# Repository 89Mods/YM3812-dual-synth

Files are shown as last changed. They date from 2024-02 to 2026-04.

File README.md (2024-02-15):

# YM3812-dual-synth
MIDI synthesizer built from two YM3812s for 18-voice mono or 9-voice stereo. More info: https://tholin.dev/ym3812d/

# Build instructions

## PCB

The gerber file for the synthesizer can be found [here](https://github.com/89Mods/YM3812-dual-synth/tree/main/KiCad/production) and you should be able to use this with all the major board houses. Just make sure they correctly recognize it as a 4-layer PCB. The dimensions of the PCB are low enough to where it should be cheap despite it being 4-layers (8€ on JLCPCB).

## Parts

The YM3812s and their DACs are the most annoying parts to obtain. They can be easily found on eBay and AliExpress by simply using "YM3812" and "Y3014" keywords, but the condition of the parts can vary. The AliExpress listings I bought from are [here](https://de.aliexpress.com/item/1005001723547967.html) and [here.](https://de.aliexpress.com/item/1005002637379806.html)

The nanoCH32V003 mini dev board you can maybe even find at your favorite maker shop, but also [on AliExpress](https://de.aliexpress.com/item/1005005221751705.html). If there is an option to buy the board plus a "WCHLinkE" you may use that (recommended), but I will also show you how to use an Arduino Uno to flash the synthesizer firmware later on (though this requires a Linux install or WSL).

All the other integrated circuits can be found at various electronics retailers:

LM358: [TME](https://www.tme.eu/de/details/lm358ap/tht-operationsverstarker/texas-instruments/) - [Mouser](https://www.mouser.de/ProductDetail/Texas-Instruments/LM358N-NOPB?qs=QbsRYf82W3GXbWt%2FvwDTcQ%3D%3D) - [LCSC](https://www.lcsc.com/product-detail/Operational-Amplifier_HGSEMI-LM358N_C434570.html)

6N139 (or 6N138): [TME](https://www.tme.eu/de/details/6n139-eve/optokoppler-analogausgang/everlight/6n139/) - [Mouser](https://www.mouser.de/ProductDetail/Vishay-Semiconductors/6N139?qs=WHRYDAs2thAk3qh0MF5UBQ%3D%3D) - [LCSC](https://www.lcsc.com/product-detail/Optocouplers-Logic-Output_CT-Micro-International-6N139_C191869.html)

SN74LV1T34DBVRG4: [TME](https://www.tme.eu/de/details/sn74lv1t34dbvrg4/logische-wandler/texas-instruments/) - [Mouser](https://www.mouser.de/ProductDetail/Texas-Instruments/SN74LV1T34DBVRG4?qs=vdi0iO8H4N10R%252Bt%252BjmxZrg%3D%3D) - [LCSC](https://www.lcsc.com/product-detail/Buffer-Driver-Transceiver_Texas-Instruments-SN74LV1T34DBVR_C100024.html)

MX25L1005 (or MX25L2006 or 25Q32 or any spiflash that supports the 25xx command set and is made by Winbond or Macronix): [TME](https://www.tme.eu/de/details/mx25l2006em1i-12g/serielle-flash-speicher/macronix-international/mx25l2006em1i-12g-tube/) - [LCSC](https://www.lcsc.com/product-detail/NOR-FLASH_MXIC-Macronix-MX25L2006EM1I-12G_C135940.html) - I also recommend looking for "MX25L1005" on AliExpress, you can get them really cheap there.

74HCT164 (or 74LS164, NOT 74HC164): [TME](https://www.tme.eu/de/details/cd74hct164e/schieberegister/texas-instruments/) - [Mouser](https://www.mouser.de/ProductDetail/Texas-Instruments/SN74LS164NE4?qs=SL3LIuy2dWzMustM9SNFlQ%3D%3D) - [LCSC](https://www.lcsc.com/product-detail/Shifting-Register_Texas-Instruments-SN74LS164N_C129807.html)

## Build notes

The BOM for assembling the board is available [here](https://example.com/). Otherwise, there is little special to keep in mind, just solder the SMD components first, and use pin sockets for the nanoCH. It needs to be removed from the synthesizer to be re-flashed.

The 5-pin header at the bottom of the board is where MIDI input is. You will need to wire in a broken-out MIDI connector here. Only two need to actually be wired up. The 2nd pin from the left wires to the Current Sink on the MIDI connector and the 4th pin from the left to Current Source.

## Flashing Firmware

This step changes depending on if you’re running Windows or Linux, and if you have bought the WCHLinkE. In any case, you will need the minichlink utility.

If you are running Linux, it is part of a repo [here](https://github.com/cnlohr/ch32v003fun/tree/master/minichlink) and can be built using the makefile there. Also read the readme there for instructions on installing the required udev rules.

If you are running windows, download the pre-built executable files [here](https://github.com/cnlohr/ch32v003fun/blob/master/minichlink/minichlink.exe) and [here](https://github.com/cnlohr/ch32v003fun/blob/master/minichlink/libusb-1.0.dll) (you need both files).

A pre-built binary of the synthesizer’s firmware is [here](https://github.com/89Mods/YM3812-dual-synth/blob/main/RV_Firmware/synth.bin). To use a WCH-LinkE to flash it, wire up the single-wire IO pin of the programmer (labeled "SWDIO" or similar) to the SWIO pin of the nanoCH (the middle of the three-pin header on the back). To then use it to flash the firmware file, the command-line `minichlink(.exe) -w synth.bin flash -b` should work on either OS, and you are already done.

If you did not buy the WCHLinkE, but have an Arduino Uno laying around, you can use Ardulink. It is available on its own repo [here](https://gitlab.com/BlueSyncLine/arduino-ch32v003-swio). Follow the instructions there to set it up. Note that it requires a Linux install or WSL to build, but can be *used* from either OS.
Additionally, the repo mentions connecting the nanoCH’s power to an Arduino pin, but I’ve found that to be really unstable and it still works fine with the nanoCH powered continuously. You only need to wire up SWIO to the Arduino (its the middle pin of the three-pin header on top).

On Windows: `minichlink.exe -c COMx -w synth.bin flash -b` where "COMx" needs to be substituted with whichever COM port your Arduino uses.

On Linux: `minichlink -c /dev/ttyACMx -w synth.bin flash -b` where "ttyACMx" needs to be substituted with whichever tty port your Arduino uses.

## Uploading patches

A set of patches for all standard MIDI instruments must be uploaded to the synthesizer at least once. A public-domain file containing patches is included in this repo: [GENMIDI.op2](https://github.com/89Mods/YM3812-dual-synth/blob/main/PatchUploader/GENMIDI.op2). You can edit this to your liking using the [OPL3 Bank Editor](https://github.com/Wohlstand/OPL3BankEditor) (scroll down and use one of the "Fresh dev builds", the latest GitHub release is years old and has issues).

A custom tool I made can then be used to send this data to the synthesizer over the MIDI port. [PatchUploader.jar](https://github.com/89Mods/YM3812-dual-synth/blob/main/PatchUploader/PatchUploader.jar) (requires Java 11 or higher). If your system does not already associate .jar files with Java, you may need to run it through a command line with `java -jar PatchUploader.jar`

The UI should be straight forward. After selecting the the .op2 file and the MIDI port of the synthesizer, click the upload button and you should see activity on the synthesizer in the form of a flashing blue LED on the nanoCH. It should flash multiple times and the synth should then reset and play a jingle. If nothing happens, check if the MIDI port is wired up correctly and if any software or hardware in your setup is potentially blocking the sysex messages used by the uploader.

The uploader software releases the MIDI port when it is done, meaning you can keep it open and use it multiple times by just clicking the button again. The file is also re-loaded each time and does not need to be selected again.

## Switching Modes

The synthesizer can operate in three distinct modes.

**Mono**: both sound chips are combined into a single output. This allows their voices to be used together, 18 in total. This is the most basic and default mode.

**Stereo**: every note is played on both chips simultaniously, but its volume on either chip is adjusted according to the MIDI channel’s stereo pan, giving the illusion of stereo audio. This, however, reduced the amount of usable voices back to 9.

**Independent**: each chip acts as a separate synthesizer. Each responds only to events on a specific range of MIDI channels and their outputs can be individually obtained on the same output as the stereo audio.

MIDI sysex messages are used to switch between these. The codes are as follows:

Switch to Mono: `0xF0 0x7E 0x56 0x72 0xF7`

Switch to Stereo: `0xF0 0x7E 0x56 0x76 0xF7`

Switch to Independent: `0xF0 0x7E 0x56 0x75 0xF7`

By default, the synthesizer listens to all channels in Mono and Stereo modes and in Independent mode, channels 1 - 8 will go to the first chip and 9 - 16 to the second. An alternative firmware image is available [here](https://github.com/89Mods/YM3812-dual-synth/blob/main/RV_Firmware/synth_alt.bin) where the synthesizer only listens to channel 15 in Mono and Stereo and in Independent, channel 14 goes to the first and channel 15 to the second chip.

To fully customize this behavior, you will need to build the firmware yourself, after editing `synth.c` and changing the values in the `accepted_channels` array for Mono and Stereo and `accepted_channels_first` and `accepted_channels_second` for Independent. These are right at the beginning of the file and are just lists of MIDI channels (warning: 0-indexed).

## Building the firmware from source

If you want to build the firmware from source, it has do be done on a native Linux install, or in Windows Subsystem for Linux. You will need to install the [RISC-V GNU Toolchain](https://github.com/riscv-collab/riscv-gnu-toolchain) first, though this step varies between distros. I recommend cloning the repo and building it from source, as that is what worked for me.

Then, clone this repo and execute the script to set up the environment: `sh clone_subrepos_and_patch.sh`

Then, you can enter the RV_Firmware directory and use the makefile there. Simply `make` will both build the firmware and then flash the output using minichlink.

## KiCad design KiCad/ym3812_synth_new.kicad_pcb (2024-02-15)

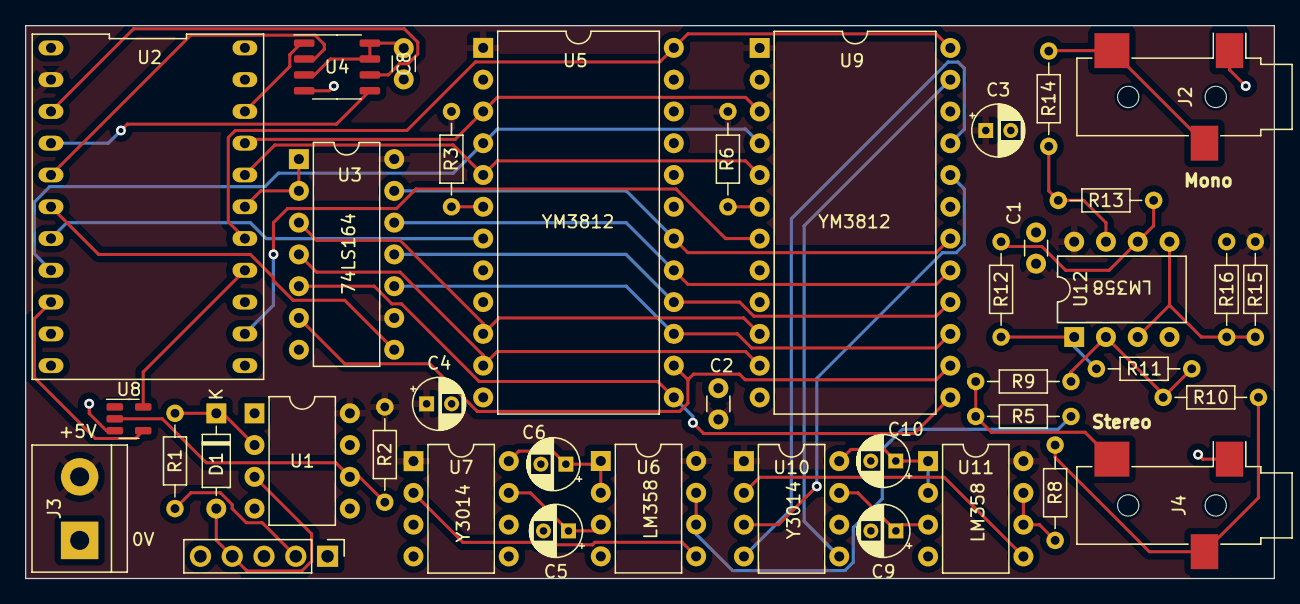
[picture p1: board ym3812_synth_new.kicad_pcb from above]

Board: 4 copper layers, 99.8 x 44.2 mm, 40 parts (0 on the bottom side), 52 nets.

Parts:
C1, C2, C8: 100nF; C_Disc_D3.0mm_W1.6mm_P2.50mm
C3, C4, C5, C6, C9, C10: 10µF; CP_Radial_D4.0mm_P2.00mm
D1: 1N4148; D_DO-35_SOD27_P7.62mm_Horizontal
J1: DIN-5; PinHeader_1x05_P2.54mm_Vertical
J2, J4: AudioJack3; Jack_3.5mm_CUI_SJ-3523-SMT_Horizontal
J3: Screw_Terminal_01x02; TerminalBlock_bornier-2_P5.08mm
R1, R2, R3, R6: 220; R_Axial_DIN0204_L3.6mm_D1.6mm_P7.62mm_Horizontal
R5, R8, R14: 1K; R_Axial_DIN0204_L3.6mm_D1.6mm_P7.62mm_Horizontal
R9, R10, R11, R12, R13: 100K; R_Axial_DIN0204_L3.6mm_D1.6mm_P7.62mm_Horizontal
R15, R16: 10K; R_Axial_DIN0204_L3.6mm_D1.6mm_P7.62mm_Horizontal
U1: 6N139; DIP-8_W7.62mm
U2: nanoCH32V003; DIP-22_610_ELL
U3: 74HCT164; DIP-14_W7.62mm
U4: MX25L1005; SOP-8_3.9x4.9mm_P1.27mm
U5, U9: YM3812; DIP-24_W15.24mm
U6, U11, U12: LM358; DIP-8_W7.62mm
U7, U10: Y3014; DIP-8_W7.62mm
U8: SN74LV1T34DCK; SOT-23-5

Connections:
4MHz: U2.16 (D0), U5.24 (φM), U9.24 (φM)
+3.3V: C8.1, U2.15 (3V3), U4.3 (~WP), U4.7 (~HOLD), U4.8 (Vcc), U8.5 (VCC)
+5V: C1.1, C2.1, C3.1, C4.1, J3.2, R2.2, R3.2, R6.2, R15.1, U1.8 (VCC), U2.2 (5V), U3.9 (~MR), U3.14 (VCC), U5.1 (Vss), U6.8 (V+), U7.1 (Vcc), U9.1 (Vss), U10.1 (Vcc), U11.8 (V+), U12.8 (V+)
A0: U2.8 (D4), U5.4 (A0), U9.4 (A0)
GND: C1.2, C2.2, C3.2, C4.2, C5.2, C6.2, C8.2, C9.2, C10.2, J2.S, J3.1, J4.S, R16.2, U1.5 (GND), U2.1 (GND), U2.22 (GND), U3.7 (GND), U4.4 (GND), U5.12 (GND), U6.4 (V-), U7.6 (GND), U8.3 (GND), U9.12 (GND), U10.6 (GND), U11.4 (V-), U12.4 (V-)
unnamed: D1.2 (A), J1.4, U1.3 (C2)
unnamed: D1.1 (K), R1.2, U1.2 (C1)
unnamed: J1.2, R1.1
unnamed: J2.R, J2.T, R14.1
unnamed: R11.1, R12.2, U12.1
unnamed: R13.1, R14.2, U12.7
unnamed: R2.1, U1.6 (VO2), U8.2 (A)
unnamed: U2.17 (C0), U3.1 (DSA), U3.2 (DSB)
unnamed: U2.6 (D2), U3.8 (CP)
unnamed: U2.9 (D5), U8.4 (Y)
unnamed: U5.21 (MO), U7.4 (SD)
unnamed: U5.20 (SH), U7.3 (LD)
unnamed: R3.1, U5.6 (~RD)
unnamed: U5.23 (φSY), U7.5 (CLK)
unnamed: C5.1, U6.3 (+), U7.7 (RB)
unnamed: C6.1, U6.1, U6.2 (-), U7.8 (MP)
unnamed: U6.5 (+), U7.2 (Out)
unnamed: R5.2, U6.6 (-), U6.7
unnamed: R6.1, U9.6 (~RD)
unnamed: U9.23 (φSY), U10.5 (CLK)
unnamed: U9.20 (SH), U10.3 (LD)
unnamed: C10.1, U10.8 (MP), U11.1, U11.2 (-)
unnamed: U10.2 (Out), U11.5 (+)
unnamed: C9.1, U10.7 (RB), U11.3 (+)
unnamed: U9.21 (MO), U10.4 (SD)
unnamed: R8.2, U11.6 (-), U11.7
unnamed: R15.2, R16.1, U12.3 (+), U12.5 (+)
unnamed: R9.1, R10.1, R11.2, U12.2 (-)
unnamed: R12.1, R13.2, U12.6 (-)
Q0: U3.3 (Q0), U5.10 (D0), U9.10 (D0)
Q1: U3.4 (Q1), U5.11 (D1), U9.11 (D1)
Q2: U3.5 (Q2), U5.13 (D2), U9.13 (D2)
Q3: U3.6 (Q3), U5.14 (D3), U9.14 (D3)
Q4: U3.10 (Q4), U5.15 (D4), U9.15 (D4)
Q5: U3.11 (Q5), U5.16 (D5), U9.16 (D5)
Q6: U3.12 (Q6), U5.17 (D6), U9.17 (D6)
Q7: U3.13 (Q7), U5.18 (D7), U9.18 (D7)
S1: J4.T, R5.1, R9.2
S2: J4.R, R8.1, R10.2
SCLK: U2.3 (C5), U4.6 (SCLK)
SI: U2.5 (C7), U4.2 (SO)
SO: U2.4 (C6), U4.5 (SI)
~CS1: U2.7 (D3), U5.7 (~CS)
~CS2: U2.13 (A1), U9.7 (~CS)
~CS: U2.20 (C3), U4.1 (~CS)
~IC: U2.19 (C2), U5.3 (~IC), U9.3 (~IC)
~WR: U2.18 (C1), U5.5 (~WR), U9.5 (~WR)

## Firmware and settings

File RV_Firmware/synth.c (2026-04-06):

#include "ch32fun.h"

#include <stdint.h>

#include "./ch32fun/extralibs/ch32v003_SPI.h"
#include "ch32v003_uart.h"
#include "spiflash.h"

#include "patch.h"
#include "YM3812.h"
#include "fixedpoint.h"

#ifdef THORINAIR
const uint8_t accepted_channels[] = {14};
const uint8_t accepted_channels_first[] = {13};
const uint8_t accepted_channels_second[] = {14};
#else
const uint8_t accepted_channels[] = {0, 1, 2, 3, 4, 5, 6, 7, 8, 9, 10, 11, 12, 13, 14, 15};
const uint8_t accepted_channels_first[] = {0, 1, 2, 3, 4, 5, 6, 7};
const uint8_t accepted_channels_second[] = {8, 9, 10, 11, 12, 13, 14, 15};
#endif

typedef struct {
	uint8_t block;
	uint16_t fnum;
} frequency_s;

frequency_s optimal_settings_for_freq(fixed32 frequency);
fixed32 key_frequency(uint8_t key, uint8_t bend);
void set_freq(ym3812_i* chip, uint8_t channel, fixed32 frequency);
void set_key(ym3812_i* chip, uint8_t midi_channel, uint8_t channel, uint8_t key);

void sound_test();
void load_patches_from_midi();

uint8_t all_ym_channel_notes[YM3812_NUM_CHANNELS*2]; //Mapping YM3812 channels -> MIDI note playing in it. >= 128 = OFF
uint8_t all_ym_channel_channels[YM3812_NUM_CHANNELS*2]; //Mapping YM3812 channels -> MIDI channels
uint32_t all_ym_channel_change_steps[YM3812_NUM_CHANNELS*2]; //Timesteps since last change to a channel’s state
uint8_t all_ym_reloads[YM3812_NUM_CHANNELS*2];
uint8_t all_to_turn_on[YM3812_NUM_CHANNELS*2];

//These are global
uint8_t stereo_mode = 0;
uint8_t independent_mode = 0;
uint8_t midi_channel_programs[16]; //Mapping MIDI channel -> MIDI program no.
patch midi_channel_patches[16];
uint8_t channel_pitch_bends[16];
uint8_t midi_channel_pans[16]; //Mapping MIDI channel -> stereo pan

typedef struct {
	uint8_t num_channels;
	uint8_t *ym_channel_notes;
	uint8_t *ym_channel_channels;
	uint32_t *ym_channel_change_steps;
	uint32_t ym_curr_timestep;
	uint8_t *to_turn_on;
	uint8_t chip_base;
	uint8_t *ym_reloads;
} synth_state;

static uint8_t wait_for_uart_data(uint8_t timeout);
void playNote(uint8_t channel, uint8_t note, uint8_t velocity, synth_state* state);
void releaseNote(uint8_t channel, uint8_t note, synth_state* state);
patch get_patch_for(uint8_t program, uint8_t drum);
void releaseAllNotes(synth_state* state);
uint8_t isAcceptedChannel(uint8_t channel);

ym3812_i chips[2];
synth_state mono_state;
synth_state stereo_state;
synth_state independent_states[2];

uint8_t isAcceptedChannel(uint8_t channel) {
	if(independent_mode) {
		for(uint8_t i = 0; i < sizeof(accepted_channels_first); i++) {
			if(channel == accepted_channels_first[i]) return 1;
		}
		for(uint8_t i = 0; i < sizeof(accepted_channels_second); i++) {
			if(channel == accepted_channels_second[i]) return 2;
		}
		return 0;
	}
	
	if(sizeof(accepted_channels) >= 16) return 1;
	for(uint8_t i = 0; i < sizeof(accepted_channels); i++) {
		if(channel == accepted_channels[i]) return 1;
	}
	return 0;
}

int main() {
	SystemInit();
	funGpioInitAll();
	UART_init();
	funPinMode(LED, GPIO_Speed_10MHz | GPIO_CNF_OUT_PP);
	funPinMode(PD5, GPIO_CNF_IN_FLOATING);
	funDigitalWrite(LED, FUN_LOW);
	Delay_Ms(500);
	funDigitalWrite(LED, FUN_HIGH);
	ym3812_init_clock();
	chips[0].cs_port = 0;
	chips[1].cs_port = 1;
	ym3812_reset(chips);
	ym3812_reset(chips + 1);
	
	{
		uint8_t chipID = init_spi();
		//spiflash did not respond correctly to identify command
		if(chipID != 0xEF && chipID != 0xC2) {
			while(1) {
				funDigitalWrite(LED, FUN_HIGH);
				Delay_Ms(500);
				funDigitalWrite(LED, FUN_LOW);
				Delay_Ms(500);
			}
		}
		//Get current mode
		rom_begin_read(0x1100);
		for(int i = 0; i < 4; i++) all_ym_channel_channels[i] = SPI_transfer_8(0);
		rom_finish_read();
		if(all_ym_channel_channels[0] != 0x06 || all_ym_channel_channels[1] != 0x21) {
			stereo_mode = independent_mode = 0;
		}else {
			stereo_mode = all_ym_channel_channels[2];
			independent_mode = all_ym_channel_channels[3];
			if(independent_mode) stereo_mode = 0;
		}
	}
	
soft_reset:
	mono_state = (synth_state){.ym_reloads = all_ym_reloads, .chip_base = 0, .num_channels = YM3812_NUM_CHANNELS*2, .ym_channel_notes = all_ym_channel_notes, .ym_channel_channels = all_ym_channel_channels, .ym_channel_change_steps = all_ym_channel_change_steps, .ym_curr_timestep = 2, .to_turn_on = all_to_turn_on};
	stereo_state = (synth_state){.ym_reloads = all_ym_reloads, .chip_base = 0, .num_channels = YM3812_NUM_CHANNELS, .ym_channel_notes = all_ym_channel_notes, .ym_channel_channels = all_ym_channel_channels, .ym_channel_change_steps = all_ym_channel_change_steps, .ym_curr_timestep = 2, .to_turn_on = all_to_turn_on};
	independent_states[0] = (synth_state){.ym_reloads = all_ym_reloads, .chip_base = 0, .num_channels = YM3812_NUM_CHANNELS, .ym_channel_notes = all_ym_channel_notes, .ym_channel_channels = all_ym_channel_channels, .ym_channel_change_steps = all_ym_channel_change_steps, .ym_curr_timestep = 2, .to_turn_on = all_to_turn_on};
	independent_states[1] = (synth_state){.ym_reloads = all_ym_reloads + YM3812_NUM_CHANNELS, .chip_base = 1, .num_channels = YM3812_NUM_CHANNELS, .ym_channel_notes = all_ym_channel_notes + YM3812_NUM_CHANNELS, .ym_channel_channels = all_ym_channel_channels + YM3812_NUM_CHANNELS, .ym_channel_change_steps = all_ym_channel_change_steps + YM3812_NUM_CHANNELS, .ym_curr_timestep = 2, .to_turn_on = all_to_turn_on + YM3812_NUM_CHANNELS};
	
	{
		//Save current mode
		sector_erase(1);
		rom_begin_write(0x1100);
		all_ym_channel_channels[0] = 0x06;
		all_ym_channel_channels[1] = 0x21;
		all_ym_channel_channels[2] = stereo_mode;
		all_ym_channel_channels[3] = independent_mode;
		rom_write_data(all_ym_channel_channels, 4);
		rom_finish_write();
	}
	
	//TODO: use memset here
	for(uint8_t i = 0; i < YM3812_NUM_CHANNELS*2; i++) {
		all_ym_channel_notes[i] = 255;
		all_ym_channel_channels[i] = 0;
		all_ym_channel_change_steps[i] = 1;
		all_to_turn_on[i] = 0;
		all_ym_reloads[i] = 0;
	}
	midi_channel_patches[0] = get_patch_for(0, 0);
	for(uint8_t i = 0; i < 16; i++) {
		midi_channel_programs[i] = 0;
		if(i != 0) midi_channel_patches[i] = midi_channel_patches[0];
		channel_pitch_bends[i] = 0;
		midi_channel_pans[i] = 64;
	}
	for(uint8_t i = 0; i < YM3812_NUM_CHANNELS; i++) {
		ym3812_loadPatch(chips, i, midi_channel_patches);
		ym3812_loadPatch(chips + 1, i, midi_channel_patches);
	}
	sound_test();
	
	synth_state *s = stereo_mode ? &stereo_state : &mono_state;
	while(1) {
		funDigitalWrite(LED, FUN_LOW);
		uint8_t next = 0;
		for(uint8_t i = 0; i < YM3812_NUM_CHANNELS*2; i++) {
			if(next == YM3812_NUM_CHANNELS) next = 0;
			if(all_to_turn_on[i]) ym3812_keyOn(chips + (i >= YM3812_NUM_CHANNELS), next, 1);
			all_to_turn_on[i] = 0;
			next++;
		}
		next = wait_for_uart_data(0);
		if((next & 128) == 0) continue;
		while(1) {
#ifndef NO_LED
			funDigitalWrite(LED, FUN_HIGH);
#endif
			uint8_t upper = next >> 4;
			uint8_t channel = next & 0b1111;
			if(upper == 0b1000) {
				//Note Off event
				uint8_t key = wait_for_uart_data(1);
				wait_for_uart_data(1); //velocity, ignored
				if(!independent_mode) {
					if(key != 255 && isAcceptedChannel(channel)) releaseNote(channel, key & 127, s);
				}else if(key != 255) {
					uint8_t idx = isAcceptedChannel(channel);
					if(idx == 1) releaseNote(channel, key & 127, independent_states);
					else if(idx == 2) releaseNote(channel, key & 127, independent_states + 1);
				}
			}else if(upper == 0b1001) {
				//Note On event
				uint8_t key = wait_for_uart_data(1);
				uint8_t velocity = wait_for_uart_data(1);
				if(!independent_mode) {
					if(key != 255 && velocity != 255 && isAcceptedChannel(channel)) {
						if(velocity == 0) releaseNote(channel, key & 127, s);
						else playNote(channel, key & 127, velocity & 127, s);
					}
				}else if(key != 255 && velocity != 255) {
					uint8_t idx = isAcceptedChannel(channel);
					if(idx == 1) {
						if(velocity == 0) releaseNote(channel, key & 127, independent_states);
						else playNote(channel, key & 127, velocity & 127, independent_states);
					}else if(idx == 2) {
						if(velocity == 0) releaseNote(channel, key & 127, independent_states + 1);
						else playNote(channel, key & 127, velocity & 127, independent_states + 1);
					}
				}
			}else if(upper == 0b1100) {
				//Program Change
				uint8_t program = wait_for_uart_data(1);
				if(program != 255) {
					if(!independent_mode) {
						if(isAcceptedChannel(channel)) {
							program &= 127;
							midi_channel_programs[channel] = program;
							midi_channel_patches[channel] = get_patch_for(program, 0);
							for(uint8_t i = 0; i < s->num_channels; i++) if(s->ym_channel_channels[i] == channel) s->ym_reloads[i] = 1;
						}
					}else {
						program &= 127;
						midi_channel_programs[channel] = program;
						midi_channel_patches[channel] = get_patch_for(program, 0);
						uint8_t idx = isAcceptedChannel(channel);
						if(idx == 1 || idx == 2) {
							synth_state *s2 = idx == 1 ? independent_states : independent_states + 1;
							for(uint8_t i = 0; i < s2->num_channels; i++) if(s2->ym_channel_channels[i] == channel) s2->ym_reloads[i] = 1;
						}
					}
				}
			}else if(upper == 0b1110) {
				//Pitch Bend Change
				wait_for_uart_data(1);
				wait_for_uart_data(1);
				if(!independent_mode) {
					if(isAcceptedChannel(channel)) {
						//TODO
					}
				}else {
					
				}
			}else if(upper == 0b1011) {
				//Channel Mode Message
				uint8_t c = wait_for_uart_data(1);
				uint8_t v = wait_for_uart_data(1);
				if(!independent_mode) {
					if(isAcceptedChannel(channel)) {
						if((c == 120 && v == 0) || (c == 123 && v == 0)) {
							//All off!
							releaseAllNotes(s);
						}
						if((c == 8 || c == 10) && stereo_mode) {
							//Stereo pan
							midi_channel_pans[channel] = v & 0b0111111;
						}
					}
				}else {
					uint8_t idx = isAcceptedChannel(channel);
					if(idx != 0) {
						if((c == 120 && v == 0) || (c == 123 && v == 0)) {
							releaseAllNotes(idx == 1 ? independent_states : independent_states + 1);
						}
					}
				}
			}else if(upper == 0b1010 || next == 0b11110010) {
				//Unsupported two-argument events
				wait_for_uart_data(1);
				wait_for_uart_data(1);
			}else if(upper == 0b1101 || next == 0b11110001 || next == 0b11110011) {
				//Unsupported single-argument events
				wait_for_uart_data(1);
			}else if(next == 0b11110000) {
				//System Exclusive
				uint8_t mid = wait_for_uart_data(1);
				if(mid == 0b01111110) {
					uint8_t id1 = wait_for_uart_data(1);
					uint8_t id2 = wait_for_uart_data(1);
					//New patches
					if(id1 == 0b01010110 && id2 == 0b01111100) {
						releaseAllNotes(s);
						load_patches_from_midi();
						goto soft_reset;
					}
					while(mid != 0b11110111) mid = wait_for_uart_data(1);
					//Sector ERASE
					if(id1 == 0b01010110 && id2 == 0b01110011) sector_erase(0);
					//Chip ERASE
					if(id1 == 0b01010110 && id2 == 0b01111011) chip_erase();
					//Switch to MONO
					if(id1 == 0b01010110 && id2 == 0b01110010) {
						stereo_mode = 0;
						goto soft_reset;
					}
					//Switch to STEREO
					if(id1 == 0b01010110 && id2 == 0b01110110) {
						stereo_mode = 1;
						goto soft_reset;
					}
					//Switch to INDEPENDENT
					if(id1 == 0b01010110 && id2 == 0b01110101) {
						stereo_mode = 0;
						independent_mode = 1;
						goto soft_reset;
					}
				}
			}else if(next == 0b11111111) {
				//Full reset
				releaseAllNotes(s);
				ym3812_reset(chips);
				ym3812_reset(chips + 1);
				goto soft_reset;
			}
			uint16_t a = UART_getc();
			if(a == UART_NO_DATA) break;
			next = a & 0xFF;
		}
	}
}

static uint8_t wait_for_uart_data(uint8_t timeout) {
	uint16_t in = UART_NO_DATA;
	uint32_t counter = 0;
	while(in == UART_NO_DATA) {
		in = UART_getc();
		counter++;
		if(timeout) {
			if(counter == 750000) Delay_Us(1);
			if(counter == 2000000) return 0xFF;
		}
	}
	in &= 0xFF;
	return in;
}

void releaseAllNotes(synth_state* state) {
	for(uint8_t i = 0; i < state->num_channels; i++) state->ym_reloads[i] = 1;
	for(uint8_t i = 0; i < state->num_channels; i++) {
		if((state->ym_channel_notes[i] & 128) == 0) releaseNote(state->ym_channel_channels[i], state->ym_channel_notes[i], state);
	}
}

void sound_test() {
	uint8_t both = stereo_mode || independent_mode;
	both++;
	for(uint8_t i = 0; i < both; i++) {
		ym3812_frqBlock(chips + i, 0, 4);
		ym3812_frqBlock(chips + i, 1, 4);
		ym3812_frqBlock(chips + i, 2, 4);
		ym3812_frqBlock(chips + i, 3, 4);
		ym3812_frqFnum(chips + i, 0, 0x1C9);
		ym3812_frqFnum(chips + i, 1, 0x240);
		ym3812_frqFnum(chips + i, 2, 0x2AD);
		ym3812_frqFnum(chips + i, 3, 0x360);
	}
	
	ym3812_keyOn(chips, 0, 1);
	if(stereo_mode) ym3812_keyOn(chips + 1, 0, 1);
	Delay_Ms(100);
	ym3812_keyOn(chips, 1, 1);
	if(stereo_mode) ym3812_keyOn(chips + 1, 1, 1);
	Delay_Ms(100);
	ym3812_keyOn(chips, 2, 1);
	if(stereo_mode) ym3812_keyOn(chips + 1, 2, 1);
	Delay_Ms(100);
	ym3812_keyOn(chips, 3, 1);
	if(stereo_mode) ym3812_keyOn(chips + 1, 3, 1);
	Delay_Ms(1000);
	for(uint8_t i = 0; i < both; i++) {
		ym3812_keyOn(chips + i, 0, 0);
		ym3812_keyOn(chips + i, 1, 0);
		ym3812_keyOn(chips + i, 2, 0);
		ym3812_keyOn(chips + i, 3, 0);
	}
	Delay_Ms(2500);
}

void playNote(uint8_t channel, uint8_t note, uint8_t velocity, synth_state* state) {
	if(note > 127) return;
	if(velocity > 127) return;
	if(channel > 15) return;
	if(channel == 9 && (note < 35 || note >= 35+47)) return;
	
	//Find the oldest inactive channel
	uint32_t min = 0xFFFFFFFFUL;
	uint32_t argmin = 1000;
	ym3812_i *chip;
	for(uint8_t i = 0; i < state->num_channels; i++) {
		if((state->ym_channel_notes[i] & 128) != 0 && state->ym_channel_change_steps[i] < min) {
			min = state->ym_channel_change_steps[i];
			argmin = i;
		}
	}
	uint8_t localChannel = (argmin >= YM3812_NUM_CHANNELS) ? argmin - YM3812_NUM_CHANNELS : argmin;
	
	if(argmin == 1000) {
		//None found, just replace oldest note instead
		min = 0xFFFFFFFFUL;
		argmin = 1000;
		for(uint8_t i = 0; i < state->num_channels; i++) {
			if(state->ym_channel_change_steps[i] < min) {
				min = state->ym_channel_change_steps[i];
				argmin = i;
			}
		}
		localChannel = (argmin >= YM3812_NUM_CHANNELS) ? argmin - YM3812_NUM_CHANNELS : argmin;
		ym3812_keyOn(chips + (argmin >= YM3812_NUM_CHANNELS), localChannel, 0);
		if(stereo_mode) ym3812_keyOn(chips + 1, localChannel, 0);
		state->ym_curr_timestep++;
	}
	chip = chips + (argmin >= YM3812_NUM_CHANNELS) + state->chip_base;
	
	if(velocity > 100) velocity = 100;
	patch p = midi_channel_patches[channel];
	//original_level = 64 - p.ops[0].level
	fixed32 original_level = (fixed32)((uint32_t)(64 - p.ops[0].level) << 16);
	//scaled_level = original_level * (velocity / 100)
	fixed32 scaled_level = f_mul(original_level, f_div((fixed32)velocity << 16, 6553600 /* 100.0 in fixed-point */));
	uint8_t scaled_level_int = (uint8_t)(scaled_level >> 16);
	uint8_t new_level_l,new_level_r;
	if(stereo_mode) {
		uint8_t pan = midi_channel_pans[channel];
		if(pan == 64) new_level_l = new_level_r = scaled_level_int;
		else if(pan > 64) {
			//To the right
			new_level_r = scaled_level_int;
			//scaled_level *= 63 / (63 - (pan - 64))
			scaled_level = f_mul(scaled_level, (fixed32)(63 - (pan - 64)) << 10);
			new_level_l = (uint8_t)(scaled_level >> 16);
		}else {
			//To the left
			new_level_l = scaled_level_int;
			//scaled_level *= 63 / pan
			scaled_level = f_mul(scaled_level, (fixed32)pan << 10);
			new_level_r = (uint8_t)(scaled_level >> 16);
		}
	}else new_level_l = new_level_r = scaled_level_int;
	if(new_level_l == 0 && stereo_mode == 0) return;
	
	//Play note at channel index
	state->ym_channel_change_steps[argmin] = state->ym_curr_timestep;
	state->ym_curr_timestep++;
	
	uint8_t fixed_note = 0;
	if(channel == 9) {
		patch used_patch = get_patch_for(note - 35, 1);
		fixed_note = used_patch.fixed_note;
		ym3812_loadPatch(chip, localChannel, &used_patch);
		if(stereo_mode) ym3812_loadPatch(chip + 1, localChannel, &used_patch);
		state->ym_reloads[argmin] = 1;
	}else if(state->ym_channel_channels[argmin] != channel || state->ym_reloads[argmin]) { //Need to load patch
		fixed_note = p.fixed_note;
		ym3812_loadPatch(chip, localChannel, &p);
		if(stereo_mode) ym3812_loadPatch(chip + 1, localChannel, &p);
		state->ym_reloads[argmin] = 0;
	}
	
	set_key(chip, channel, localChannel, fixed_note != 0 ? fixed_note : note);
	if(stereo_mode) set_key(chip + 1, channel, localChannel, fixed_note != 0 ? fixed_note : note);
	state->to_turn_on[argmin] = new_level_l != 0;
	if(stereo_mode) state->to_turn_on[argmin + YM3812_NUM_CHANNELS] = new_level_r != 0;
	state->ym_channel_notes[argmin] = note;
	state->ym_channel_channels[argmin] = channel;
	
	ym3812_setLevel(chip, localChannel, 0, 64 - new_level_l);
	if(stereo_mode) ym3812_setLevel(chip + 1, localChannel, 0, 64 - new_level_r);
}

void releaseNote(uint8_t channel, uint8_t note, synth_state* state) {
	note &= 0x7F;
	channel &= 0x0F;
	
	for(uint8_t i = 0; i < state->num_channels; i++) {
		uint8_t ym_midi_channel = state->ym_channel_channels[i];
		if(ym_midi_channel != channel) continue;
		if(state->ym_channel_notes[i] != note) continue;
		
		ym3812_keyOn(chips + (i >= YM3812_NUM_CHANNELS) + state->chip_base, i >= YM3812_NUM_CHANNELS ? i - YM3812_NUM_CHANNELS : i, 0);
		state->ym_channel_change_steps[i] = state->ym_curr_timestep;
		state->ym_curr_timestep++;
		
		state->ym_channel_notes[i] = 255;
	}
}

patch get_patch_for(uint8_t program, uint8_t drum) {
	uint32_t address = (uint32_t)program * 14 + (drum ? 128 * 14 : 0);
	rom_begin_read(address);
	
	patch p;
	p.ops[0].tvenvfreq   = SPI_transfer_8(0);
	p.ops[0].level_scale = SPI_transfer_8(0);
	p.ops[0].level       = SPI_transfer_8(0);
	p.ops[0].atck_dec    = SPI_transfer_8(0);
	p.ops[0].sus_rel     = SPI_transfer_8(0);
	p.ops[0].wave        = SPI_transfer_8(0);
	p.ops[1].tvenvfreq   = SPI_transfer_8(0);
	p.ops[1].level_scale = SPI_transfer_8(0);
	p.ops[1].level       = SPI_transfer_8(0);
	p.ops[1].atck_dec    = SPI_transfer_8(0);
	p.ops[1].sus_rel     = SPI_transfer_8(0);
	p.ops[1].wave        = SPI_transfer_8(0);
	p.feedback_algo      = SPI_transfer_8(0);
	p.fixed_note         = SPI_transfer_8(0);
	
	rom_finish_read();
	return p;
}

frequency_s optimal_settings_for_freq(fixed32 frequency) {
	for(uint8_t block = 0; block < 8; block++) {
		fixed32 Ff = f_mul((fixed32)frequency, 668622 /* 10.202361081 in fixed-point */);
		if(block == 0) Ff <<= 1;
		else Ff >>= block - 1;
		uint32_t Ffi = (uint32_t)(Ff >> 16);
		if(Ffi >= 1023) continue;
		frequency_s res;
		res.block = block;
		res.fnum = (uint16_t)Ffi;
		return res;
	}
	frequency_s res;
	res.block = 0;
	res.fnum = 0;
	return res;
}

void set_freq(ym3812_i* chip, uint8_t channel, fixed32 frequency) {
	frequency_s setting = optimal_settings_for_freq(frequency);
	if(setting.block == 0 && setting.fnum == 0) return;
	ym3812_frqBlock(chip, channel, setting.block);
	ym3812_frqFnum(chip, channel, setting.fnum);
}

inline void set_key(ym3812_i* chip, uint8_t midi_channel, uint8_t channel, uint8_t key) {
	set_freq(chip, channel, key_frequency(key, channel_pitch_bends[midi_channel]));
}

const fixed32 key_frequencies[128] = { //Calculated by genlut.c via "2**((key - 69) / 12) * 440"
	0x082d01,0x08a976,0x092d51,0x09b904,
	0x0a4d05,0x0ae9d3,0x0b8ff4,0x0c3ff6,
	0x0cfa70,0x0dc000,0x0e914f,0x0f6f11,
	0x105a02,0x1152ec,0x125aa2,0x137208,
	0x149a0a,0x15d3a6,0x171fe9,0x187fed,
	0x19f4e0,0x1b8000,0x1d229e,0x1ede22,
	0x20b404,0x22a5d8,0x24b545,0x26e410,
	0x293415,0x2ba74d,0x2e3fd2,0x30ffda,
	0x33e9c0,0x370000,0x3a453d,0x3dbc44,
	0x416809,0x454bb0,0x496a8b,0x4dc820,
	0x52682a,0x574e9b,0x5c7fa4,0x61ffb5,
	0x67d380,0x6e0000,0x748a7b,0x7b7888,
	0x82d013,0x8a9760,0x92d517,0x9b9041,
	0xa4d054,0xae9d37,0xb8ff49,0xc3ff6a,
	0xcfa700,0xdc0000,0xe914f6,0xf6f110,
	0x105a026,0x1152ec0,0x125aa2e,0x1372082,
	0x149a0a8,0x15d3a6e,0x171fe92,0x187fed4,
	0x19f4e00,0x1b80000,0x1d229ec,0x1ede220,
	0x20b404c,0x22a5d80,0x24b545c,0x26e4104,
	0x2934150,0x2ba74dc,0x2e3fd24,0x30ffda8,
	0x33e9c00,0x3700000,0x3a453d8,0x3dbc440,
	0x4168098,0x454bb00,0x496a8b8,0x4dc8208,
	0x52682a0,0x574e9b8,0x5c7fa48,0x61ffb50,
	0x67d3800,0x6e00000,0x748a7b0,0x7b78880,
	0x82d0130,0x8a97600,0x92d5170,0x9b90410,
	0xa4d0540,0xae9d370,0xb8ff490,0xc3ff6a0,
	0xcfa7000,0xdc00000,0xe914f60,0xf6f1100,
	0x105a0260,0x1152ec00,0x125aa2e0,0x13720820,
	0x149a0a80,0x15d3a6e0,0x171fe920,0x187fed40,
	0x19f4e000,0x1b800000,0x1d229ec0,0x1ede2200,
	0x20b404c0,0x22a5d800,0x24b545c0,0x26e41040,
	0x29341500,0x2ba74dc0,0x2e3fd240,0x30ffda80
};

fixed32 key_frequency(uint8_t key, uint8_t bend) {
	key &= 127;
	return key_frequencies[key];
}

void load_patches_from_midi() {
	funDigitalWrite(LED, FUN_LOW);
	uint8_t patchData[14];
	uint8_t x;
	rom_begin_write(0);
	for(uint16_t i = 0; i < 176; i++) { //128 melodic + 47 drums + 1 dummy
		for(uint8_t j = 0; j < 14; j++) {
			x = wait_for_uart_data(1);
			if(x == 0b11110111 || x == 255) goto ERROR;
			patchData[j] = x;
			if(!(j == 5 || j == 11 || j == 12 || j == 13)) { //These can be expressed in just 7 bits
				x = wait_for_uart_data(1);
				if(x == 0b11110111 || x == 255) goto ERROR;
				patchData[j] |= x << 7;
			}
		}
		rom_write_data(patchData, 14);
		if(((i + 1) & 3) == 0 && i != 175) {
			if(wait_for_uart_data(1) != 0b11110111) goto ERROR;
			if(wait_for_uart_data(1) != 0b11110000) goto ERROR;
			for(uint8_t k = 0; k < 3; k++) if(wait_for_uart_data(1) != 0) goto ERROR;
		}
	}
	rom_finish_write();
	for(uint8_t i = 0; i < 6; i++) {
		funDigitalWrite(LED, FUN_HIGH);
		Delay_Ms(50);
		funDigitalWrite(LED, FUN_LOW);
		Delay_Ms(250);
	}
	return;
ERROR:
	for(uint8_t i = 0; i < 16; i++) {
		funDigitalWrite(LED, FUN_HIGH);
		Delay_Ms(250);
		funDigitalWrite(LED, FUN_LOW);
		Delay_Ms(250);
	}
}

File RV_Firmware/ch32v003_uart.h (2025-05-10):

#ifndef _CH32V003_UART_H
#define _CH32V003_UART_H
/**
 * @file ch32v003_uart.h
 * @author Piotr Zapart
 * @brief CH32V003 generic UART library, 8N1, default 115200baud, No parity, no flow control
 * @version 0.1
 * @date 2023-07-22
 * 
 *  Caution! 
 *  ============================================================
 *  Library will not work if FUNCONF_USE_UARTPRINTF is defined!
 *  ============================================================
 * 
 *	USART1 mapping configuration high (used in conjunction with AFIO PCFR1 register bit2
 *	USART1RM [21,2]).
 * 	00: default mapping (CK/PD4, TX/PD5, RX/PD6, CTS/PD3, RTS/PC2, SW_RX/PD5).
 *	01: Remapping (CK/PD7, TX/PD0, RX/PD1, CTS/PC3, RTS/PC2, SW_RX/PD0).
 *	10: Remapping (CK/PD7, TX/PD6, RX/PD5, CTS/PC6, RTS/PC7, SW_RX/PD6).
 *	11: Remapping (CK/PC5, TX/PC0, RX/PC1, CTS/PC6, RTS/PC7, SW_RX/PC0).
 *
 * Usage:
 * 1. In funconfig.h define the baudrate:
 *    #define FUNCONF_UART_PRINTF_BAUD 115200 //used for uart library
 * 
 * 2. In main source file: optionally define the TXRX pin configuration. If not defined
 *    the standard TX=PD5, RX=PD6 is used, alternative settings:
 *    #define UART_PINS_TXPD0_RXPD1 or
 *    #define UART_PINS_TXPC0_RXPC1 or
 *    #define UART_PINS_TXPD6_RXPD5 - this is the TXRX swap setting
 * 
 * 3. X or RX can be disabled separately, for TX only UART add the following define
 *    #define UART_MODE_TX
 *    for RX only: #define UART_MODE_RX
 *    Default setting is both, TX and RX enabled
 * 	
 * 4. In main source file add
 *    #define CH32V003_UART_IMPLEMENTATION
 * 5. Then include the header file
 *    #include "ch32v003_uart.h"
 * 
 * 	To send a byte:
 * 		UART_putc(dataByte);
 * 	To print something:
 * 		UART_printf(...)
 *  To receive a byte:
 * 		uint16 in = UART_getc();
 * 	The higher byte contains error flags, function returns UART_NO_DATA if all has been 
 *  read from the receive buffer.
 *  	if( in != UART_NO_DATA )
 * 				receivedByte = in & 0xFF;
 * 
 *  TX and RX buffer sizes are set to 32 bytes. Both values have to be power of 2! 
 */
#include <stdarg.h>
#include <string.h>
#include "ch32fun.h"
// use uart only if debug printf is enables
#if defined( FUNCONF_USE_DEBUGPRINTF ) && FUNCONF_USE_DEBUGPRINTF

#define UART_TX_BF_SIZE	256	// tx buffer size, has to be power of 2!
#define UART_RX_BF_SIZE	256	// rx buffer size, has to be power of 2!

#define UART_TX_BF_MASK	(UART_TX_BF_SIZE-1)
#define UART_RX_BF_MASK	(UART_RX_BF_SIZE-1)

#if ( UART_TX_BF_SIZE & UART_TX_BF_MASK )
#error TX buffer size is not a power of 2
#endif
#if ( UART_RX_BF_MASK & UART_RX_BF_SIZE )
#error RX buffer size is not a power of 2
#endif

#define UART_IT_ERROR_MASK			(0x0E)		// FE + NE + ORE
#define UART_ERR_CHKSUM				(0x0100)	// Checksum error flag	| USART1_STATR << 8
#define UART_ERR_FRAME     			(0x0200)	// Frame error flag		|
#define UART_ERR_NOISE				(0x0400)	// Noise error flag		| 
#define UART_ERR_OVERRUN 		    (0x0800)	// Overload error flag	|
#define UART_ERR_RXBUF_OVERFLOW 	(0x0100)	// RX buffer overflow
#define UART_NO_DATA          		(0x8000) 	// No data received

#define UART_AFIO_PCFR1_RESET_MASK	(0xFFDFFFFB)	// bit 2 & bit 21 

#if defined(UART_PINS_TXPD0_RXPD1)
	#define UART_PORT_RCC	RCC_APB2Periph_GPIOD
	#define UART_PORT		GPIOD 
	#define UART_PIN_TX 	0
	#define UART_PIN_RX 	1
	#define UART_AFIO_PCFR1	(1<<2)							//remap 01
#elif defined (UART_PINS_TXPC0_RXPC1)
	#define UART_PORT_RCC	RCC_APB2Periph_GPIOC
	#define UART_PORT		GPIOC
	#define UART_PIN_TX 	0
	#define UART_PIN_RX 	1
	#define UART_AFIO_PCFR1	((1<<21)|(1<<2))				//remap 11
#elif defined (UART_PINS_TXPD6_RXPD5)
	#define UART_PORT_RCC	RCC_APB2Periph_GPIOD
	#define UART_PORT		GPIOD 
	#define UART_PIN_TX 	6
	#define UART_PIN_RX 	5
	#define UART_AFIO_PCFR1	(1<<21)							// remap 10
#else 
	#define UART_PINS_TXPD5_RXPD6
	#define UART_PORT_RCC	RCC_APB2Periph_GPIOD
	#define UART_PORT		GPIOD 
	#define UART_PIN_TX 	5
	#define UART_PIN_RX 	6
	#define UART_AFIO_PCFR1	(0)	//default 00
#endif
// if no config is provided, use tx+rx as default
#if !defined(UART_MODE_TX) && !defined(UART_MODE_RX) && !defined(UART_MODE_TXRX)
	#define UART_MODE_TXRX
#endif	

#if defined (UART_MODE_TXRX)
	#define UART_MODE_TX
	#define UART_MODE_RX
#endif

void UART_init();			// baudrate set in funconf.h using FUNCONF_UART_PRINTF_BAUD

#if defined(CH32V003_UART_IMPLEMENTATION)

#if defined(UART_MODE_TX)
	#define UART_IT_TXE_ENABLE		(0x0080)
	#define UART_IT_TXE_DISABLE		(0xFF7F)
	uint8_t uart_tx_bf[UART_TX_BF_SIZE]; // transmit buffer
	static volatile uint8_t uart_txHead, uart_txTail;
	static volatile uint16_t lastTXerrorFlag = 0;
	void UART_putc(uint8_t data);
	int UART_write(const char *buf, int size);
	static int UART_puts(char *s, int len, void *buf);
	int UART_printf(const char* format, ...);		
	int mini_vpprintf(int (*puts)(char* s, int len, void* buf), void* buf, const char *fmt, va_list va);
#endif

#if defined (UART_MODE_RX)
	#define UART_IT_RXC_ENABLE		(0x0020)
	#define UART_IT_RXC_DISABLE		(0xFFDF)
	uint8_t uart_rx_bf[UART_TX_BF_SIZE]; // transmit buffer	
	static volatile uint8_t uart_rxHead, uart_rxTail;
	static volatile uint16_t lastRXerrorFlag = 0;
	uint16_t UART_getc(void);
#endif
// --------------------------------------------------------
/**
 * @brief Initialoze USART1 with predefined settings
 */
void UART_init()
{
	uint16_t tmp16 = USART_WordLength_8b | USART_Parity_No;
	RCC->APB2PCENR |= UART_PORT_RCC | RCC_APB2Periph_USART1 | RCC_APB2Periph_AFIO;

	AFIO->PCFR1 &= UART_AFIO_PCFR1_RESET_MASK;
	AFIO->PCFR1 |= UART_AFIO_PCFR1;

#if defined(UART_MODE_TX)
	UART_PORT->CFGLR &= ~(0xf<<(4*UART_PIN_TX));
	UART_PORT->CFGLR |= (GPIO_Speed_10MHz | GPIO_CNF_OUT_PP_AF)<<(4*UART_PIN_TX);
	tmp16 |= USART_Mode_Tx;
	uart_txHead = 0;
	uart_txTail = 0;
#endif
#if defined (UART_MODE_RX)
	UART_PORT->CFGLR &= ~(0xf<<(4*UART_PIN_RX));
	UART_PORT->CFGLR |= (GPIO_Speed_10MHz | GPIO_CNF_IN_PUPD)<<(4*UART_PIN_RX);
	tmp16 |= USART_Mode_Rx | UART_IT_RXC_ENABLE;	// enable TX and rx complete interrupt
	uart_rxHead = 0;
	uart_rxTail = 0;	
#endif
	NVIC_EnableIRQ(USART1_IRQn);
	USART1->CTLR1 =  tmp16;
	USART1->CTLR2 = USART_StopBits_1;
	USART1->CTLR3 = USART_HardwareFlowControl_None;
	USART1->BRR = UART_BRR;
	USART1->CTLR1 |= CTLR1_UE_Set;	
}
// --------------------------------------------------------
#if defined (UART_MODE_RX)
/**
 * @brief  return byte from ringbuffer  
 * 
 * @return uint16_t l	lower byte:  received byte from ringbuffer
          				higher byte: last receive error
 */
uint16_t UART_getc(void)
{    
    uint8_t tmp8, data;

    if ( uart_rxHead == uart_rxTail ) return UART_NO_DATA;

    tmp8 = (uart_rxTail + 1) & UART_RX_BF_MASK;
    uart_rxTail = tmp8; 
    
    data = uart_rx_bf[tmp8];
    
    return (lastRXerrorFlag | data);
}
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

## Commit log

2024-02-01 Add existing files.
    [ym3812_synth_new.kicad_pcb, ym3812_synth_new.kicad_sch]
2024-02-15 Gerber file
    [ym3812_synth_new.kicad_pcb]
2024-03-10 Bug fixes related to mode switching.
    [spiflash.c, synth.c]
